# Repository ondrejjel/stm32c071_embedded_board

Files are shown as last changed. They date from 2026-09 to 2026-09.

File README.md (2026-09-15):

# STM32C071 Development Board

A compact, portable embedded development board built around the **STM32C071K8T6** microcontroller.

The board was designed as a personal platform for embedded firmware development, hardware experimentation, and prototyping. The focus is on providing a reasonably complete development environment in a small form factor while keeping important interfaces accessible for debugging and experimentation.

> **Status:** Rev. 1 PCB manufactured.

## Features

### MCU

* **STM32C071K8T6**
* ARM Cortex-M0+ core
* LQFP-32 package
* SWD programming and debugging
* Dedicated RESET and BOOT0 buttons

### Memory

* **16 MB SPI NOR flash**
* Winbond **W25Q128JV**
* Dedicated SPI interface
* Accessible through exposed test points

### Security

* **ATECC608A** secure element
* I²C interface
* Intended for experimentation with hardware-backed cryptography, secure key storage, and device identity

### USB

* USB-C receptacle
* USB 2.0 interface
* **USBLC6-4SC6** ESD protection

### Power

* 5 V input
* **MCP1825S-330** 3.3 V LDO
* Exposed 5 V and 3.3 V test points
* Multiple ground test points

### User Interface

* 5 user buttons
* Dedicated RESET button
* Dedicated BOOT0 button
* Dedicated red power indicator LED
* 5 user LEDs:

  * 1× red
  * 1× green
  * 1× blue
  * 1× orange
  * 1× yellow

### Debugging & Test

The board includes numerous test points to make hardware bring-up and debugging easier.

Exposed signals include:

* SWDIO
* SWCLK
* NRST
* BOOT0
* UART TX/RX
* SPI CS
* SPI CLK
* SPI DI
* SPI DO
* I²C SDA/SCL
* 5 V
* 3.3 V
* GND

An **STDC14** debug connector is also provided.

## Hardware Architecture

The main hardware blocks are:

```text
                         ┌──────────────────┐
                    -----│    USB-C Input   │
                    │    └────────┬─────────┘
                    │             │
                   USB           5 V
                    │             │
                    │    ┌────────▼─────────┐
                    │    │   Power / 3.3 V  │
                    │    │     MCP1825S     │
                    │    └────────┬─────────┘
                    │             │ 
                 ┌──▼─────────────▼────────────────┐
                 │          STM32C071K8T6           │
                 │                                 │
                 │  GPIO   SPI   I²C   USB   SWD   │
                 └───┬─────┬─────┬─────┬────┬─────┘
                     │     │     │     │    │
                     │     │     │     │    └── Debug
                     │     │     │     │
                     │     │     │     └──── USB
                     │     │     │
                     │     │     └──────── ATECC608A
                     │     │
                     │     └────────────── W25Q128JV
                     │
                     └────────────────── Buttons / LEDs
```

The exact peripheral assignments are defined in the schematic and firmware configuration.

## PCB Design

The schematic and PCB were designed entirely in **KiCad**.

The board was designed around several goals:

* compact and portable form factor
* practical access to debugging interfaces
* dedicated test points for important signals
* integrated external memory
* hardware security experimentation
* simple power architecture
* useful user I/O
* easy hardware bring-up

The PCB was manufactured by **JLCPCB**.

## Bring-up Plan

Once the assembled board is available, hardware bring-up will be performed incrementally.

### 1. Power

* Inspect the assembled PCB
* Check for shorts before applying power
* Verify 5 V input
* Verify 3.3 V regulator output
* Measure idle current consumption

### 2. MCU

* Connect through SWD
* Verify MCU identification
* Test RESET
* Verify BOOT0 operation
* Flash a minimal test program

### 3. GPIO

* Test user buttons
* Test LEDs
* Verify GPIO levels and mappings

### 4. SPI Flash

* Verify SPI signals with a logic analyzer
* Read the JEDEC ID
* Test read/write operations
* Verify the full memory interface

### 5. I²C / Secure Element

* Verify I²C electrical levels
* Detect the ATECC608A
* Establish communication
* Test basic device functionality

### 6. USB

* Verify USB power and signal integrity
* Test USB enumeration
* Develop and validate the intended USB functionality

Any hardware problems discovered during bring-up will be documented in this repository.

## Test Points

The board intentionally exposes important signals for external measurement.

| Signal | Purpose |
| --- | --- |
| GND | Ground reference |
| 5V | Main 5 V rail |
| 3V3 | Regulated 3.3 V rail |
| NRST | MCU reset |
| BOOT0 | Boot configuration |
| SWDIO | SWD data |
| SWCLK | SWD clock |
| TX | UART transmit |
| RX | UART receive |
| CS | SPI chip select |
| CLK | SPI clock |
| DI | SPI data input |
| DO | SPI data output |
| SDA | I²C data |
| SCL | I²C clock |
| USERBTN1–5 | User button signals  |

## Repository Structure

```text
.
├── hardware/
│   ├── schematic/
│   ├── pcb/
│   └── fabrication/
├── firmware/
├── docs/
├── LICENSE
└── README.md
```

The structure may evolve as firmware and documentation are added.

## Design Files

The KiCad project contains the complete schematic and PCB design.

Manufacturing files are included so that future revisions can be reproduced or modified.

## Bill of Materials

The main active components are:

| Reference | Component | Purpose |
| --- | --- | --- |
| U1 | STM32C071K8T6 | Main MCU |
| U2 | ATECC608A-SSHDA | Secure element |
| U3 | W25Q128JV | 16 MB SPI flash |
| U4 | USBLC6-4SC6 | USB ESD protection |
| U5 | MCP1825S-330E | 3.3 V LDO |
| J1 | STDC14 | Debug/programming connector |
| J2 | USB-C | USB/power connection |

The complete BOM is available in the hardware project files.

## Project Status

| Area | Status |
| --- | --- |
| Schematic | Complete |
| PCB layout | Complete |
| Manufacturing files | Complete |
| PCB manufacturing | In progress |
| Assembly | Pending |
| Hardware bring-up | Pending |
| Firmware | Planned |

## Lessons & Revision History

This is my first custom PCB project, so the first revision is also intended as a learning platform.

Rather than treating Rev. 1 as a final design, the goal is to use the board to identify:

* schematic mistakes
* layout issues
* component selection problems
* power-related issues
* signal integrity problems
* usability improvements

Findings from the first hardware revision will be documented here and used to guide future revisions.

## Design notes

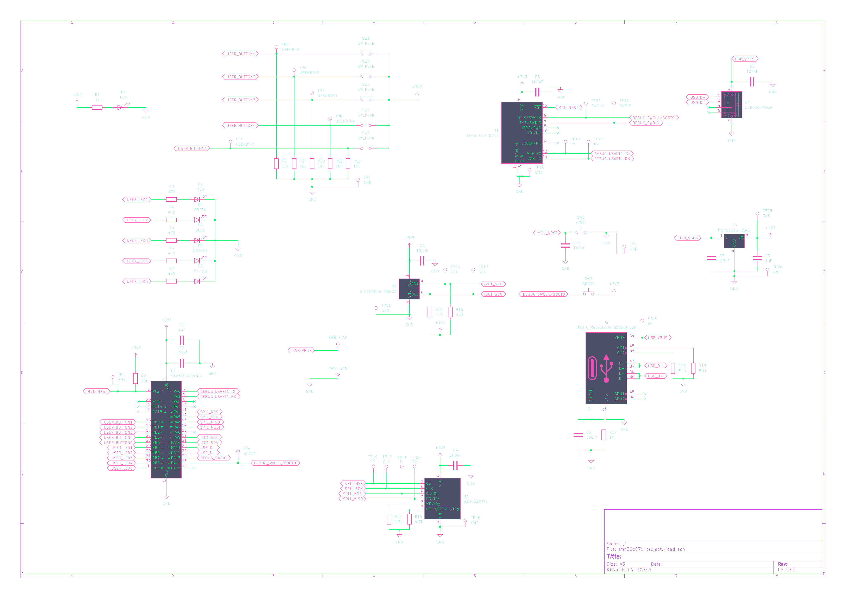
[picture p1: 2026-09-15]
hardware/schematics/image.png

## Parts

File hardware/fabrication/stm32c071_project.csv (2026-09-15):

Reference | Qty | Value | DNP | Exclude from BOM | Exclude from Board | Exclude from Simulation | Exclude from Position Files | Footprint | Datasheet
C1,C9 | 2 | 1uF |  |  |  |  | ${EXCLUDE_FROM_POS_FILES} | Capacitor_SMD:C_0603_1608Metric
C2,C3,C4,C5,C6,C8,C10 | 7 | 100nF |  |  |  |  | ${EXCLUDE_FROM_POS_FILES} | Capacitor_SMD:C_0603_1608Metric
C7 | 1 | 4.7uF |  |  |  |  | ${EXCLUDE_FROM_POS_FILES} | Capacitor_SMD:C_0603_1608Metric
D1,D2 | 2 | RED |  |  |  |  | ${EXCLUDE_FROM_POS_FILES} | LED_SMD:LED_0603_1608Metric
D3 | 1 | GREEN |  |  |  |  | ${EXCLUDE_FROM_POS_FILES} | LED_SMD:LED_0603_1608Metric
D4 | 1 | BLUE |  |  |  |  | ${EXCLUDE_FROM_POS_FILES} | LED_SMD:LED_0603_1608Metric
D5 | 1 | ORANGE |  |  |  |  | ${EXCLUDE_FROM_POS_FILES} | LED_SMD:LED_0603_1608Metric
D6 | 1 | YELLOW |  |  |  |  | ${EXCLUDE_FROM_POS_FILES} | LED_SMD:LED_0603_1608Metric
J1 | 1 | Conn_ST_STDC14 |  |  |  |  | ${EXCLUDE_FROM_POS_FILES} | Connector_PinHeader_1.27mm:PinHeader_2x07_P1.27mm_Vertical | https://www.st.com/content/ccc/resource/technical/document/user_manual/group1/99/49/91/b6/b2/3a/46/e5/DM00526767/files/DM00526767.pdf/jcr:content/translations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
J2 | 1 | USB_C_Receptacle_USB2.0_16P |  |  |  |  | ${EXCLUDE_FROM_POS_FILES} | Connector_USB:USB_C_Receptacle_GCT_USB4110 | https://www.usb.org/sites/default/files/documents/usb_type-c.zip
R1 | 1 | 1k |  |  |  |  | ${EXCLUDE_FROM_POS_FILES} | Resistor_SMD:R_0603_1608Metric
R2,R8,R9,R10,R11,R12 | 6 | 10k |  |  |  |  | ${EXCLUDE_FROM_POS_FILES} | Resistor_SMD:R_0603_1608Metric
R3,R4,R5,R6,R7 | 5 | 470 |  |  |  |  | ${EXCLUDE_FROM_POS_FILES} | Resistor_SMD:R_0603_1608Metric
R13,R14,R15,R16 | 4 | 4.7k |  |  |  |  | ${EXCLUDE_FROM_POS_FILES} | Resistor_SMD:R_0603_1608Metric
R17 | 1 | 1M |  |  |  |  | ${EXCLUDE_FROM_POS_FILES} | Resistor_SMD:R_0603_1608Metric
R18,R19 | 2 | 5.1k |  |  |  |  | ${EXCLUDE_FROM_POS_FILES} | Resistor_SMD:R_0603_1608Metric
SW1,SW2,SW3,SW4,SW5 | 5 | SW_Push |  |  |  |  | ${EXCLUDE_FROM_POS_FILES} | Button_Switch_SMD:SW_Push_SPST_NO_Alps_SKRK
SW6 | 1 | RESET |  |  |  |  | ${EXCLUDE_FROM_POS_FILES} | Button_Switch_SMD:SW_Push_SPST_NO_Alps_SKRK
SW7 | 1 | BOOT0 |  |  |  |  | ${EXCLUDE_FROM_POS_FILES} | Button_Switch_SMD:SW_Push_SPST_NO_Alps_SKRK
TP1 | 1 | NRST |  |  |  |  | ${EXCLUDE_FROM_POS_FILES} | TestPoint:TestPoint_Pad_D1.0mm
TP2,TP9,TP11,TP16,TP18,TP26 | 6 | GND |  |  |  |  | ${EXCLUDE_FROM_POS_FILES} | TestPoint:TestPoint_Pad_1.0x1.0mm
TP3 | 1 | USERBTN5 |  |  |  |  | ${EXCLUDE_FROM_POS_FILES} | TestPoint:TestPoint_Pad_D1.0mm
TP4 | 1 | BOOT0 |  |  |  |  | ${EXCLUDE_FROM_POS_FILES} | TestPoint:TestPoint_Pad_D1.0mm
TP5 | 1 | USERBTN1 |  |  |  |  | ${EXCLUDE_FROM_POS_FILES} | TestPoint:TestPoint_Pad_D1.0mm
TP6 | 1 | USERBTN2 |  |  |  |  | ${EXCLUDE_FROM_POS_FILES} | TestPoint:TestPoint_Pad_D1.0mm
TP7 | 1 | USERBTN3 |  |  |  |  | ${EXCLUDE_FROM_POS_FILES} | TestPoint:TestPoint_Pad_D1.0mm
TP8 | 1 | USERBTN4 |  |  |  |  | ${EXCLUDE_FROM_POS_FILES} | TestPoint:TestPoint_Pad_D1.0mm
TP10 | 1 | CS |  |  |  |  | ${EXCLUDE_FROM_POS_FILES} | TestPoint:TestPoint_Pad_D1.0mm
TP12 | 1 | CLK |  |  |  |  | ${EXCLUDE_FROM_POS_FILES} | TestPoint:TestPoint_Pad_D1.0mm
TP13 | 1 | DI |  |  |  |  | ${EXCLUDE_FROM_POS_FILES} | TestPoint:TestPoint_Pad_D1.0mm
TP14 | 1 | DO |  |  |  |  | ${EXCLUDE_FROM_POS_FILES} | TestPoint:TestPoint_Pad_D1.0mm
TP15 | 1 | SDA |  |  |  |  | ${EXCLUDE_FROM_POS_FILES} | TestPoint:TestPoint_Pad_D1.0mm
TP17 | 1 | SCL |  |  |  |  | ${EXCLUDE_FROM_POS_FILES} | TestPoint:TestPoint_Pad_D1.0mm
TP19 | 1 | TX |  |  |  |  | ${EXCLUDE_FROM_POS_FILES} | TestPoint:TestPoint_Pad_D1.0mm
TP20 | 1 | SWCLK |  |  |  |  | ${EXCLUDE_FROM_POS_FILES} | TestPoint:TestPoint_Pad_D1.0mm
TP21 | 1 | RX |  |  |  |  | ${EXCLUDE_FROM_POS_FILES} | TestPoint:TestPoint_Pad_D1.0mm
TP22 | 1 | SWDIO |  |  |  |  | ${EXCLUDE_FROM_POS_FILES} | TestPoint:TestPoint_Pad_D1.0mm
TP24 | 1 | 5V |  |  |  |  | ${EXCLUDE_FROM_POS_FILES} | TestPoint:TestPoint_Pad_D1.0mm
TP25 | 1 | 3V3 |  |  |  |  | ${EXCLUDE_FROM_POS_FILES} | TestPoint:TestPoint_Pad_D1.0mm
U1 | 1 | STM32C071K8Tx |  |  |  |  | ${EXCLUDE_FROM_POS_FILES} | Package_QFP:LQFP-32_7x7mm_P0.8mm | https://www.st.com/resource/en/datasheet/stm32c071k8.pdf
U2 | 1 | ATECC608A-SSHDA |  |  |  |  | ${EXCLUDE_FROM_POS_FILES} | Package_SO:SOIC-8_3.9x4.9mm_P1.27mm | http://ww1.microchip.com/downloads/en/DeviceDoc/ATECC608A-CryptoAuthentication-Device-Summary-Data-Sheet-DS40001977B.pdf
U3 | 1 | W25Q128JVS |  |  |  |  | ${EXCLUDE_FROM_POS_FILES} | Package_SO:SOIC-8_5.3x5.3mm_P1.27mm | https://www.winbond.com/resource-files/w25q128jv_dtr%20revc%2003272018%20plus.pdf
U4 | 1 | USBLC6-4SC6 |  |  |  |  | ${EXCLUDE_FROM_POS_FILES} | Package_TO_SOT_SMD:SOT-23-6 | https://www.st.com/resource/en/datasheet/usblc6-4.pdf
U5 | 1 | MCP1825S-330E |  |  |  |  | ${EXCLUDE_FROM_POS_FILES} | Package_TO_SOT_SMD:SOT-223-3_TabPin2 | http://ww1.microchip.com/downloads/en/devicedoc/22056b.pdf

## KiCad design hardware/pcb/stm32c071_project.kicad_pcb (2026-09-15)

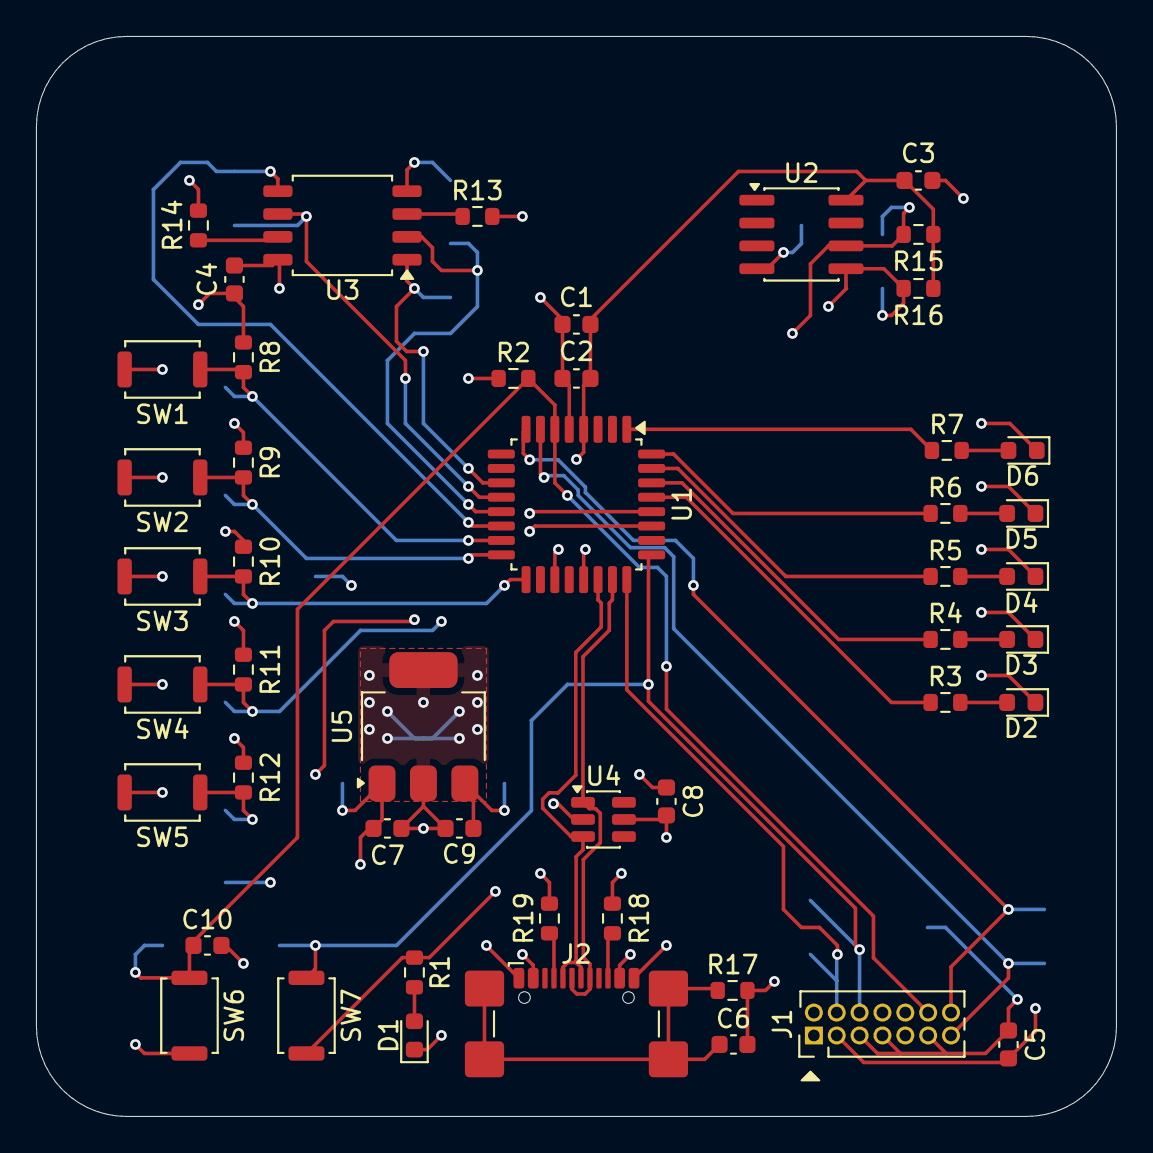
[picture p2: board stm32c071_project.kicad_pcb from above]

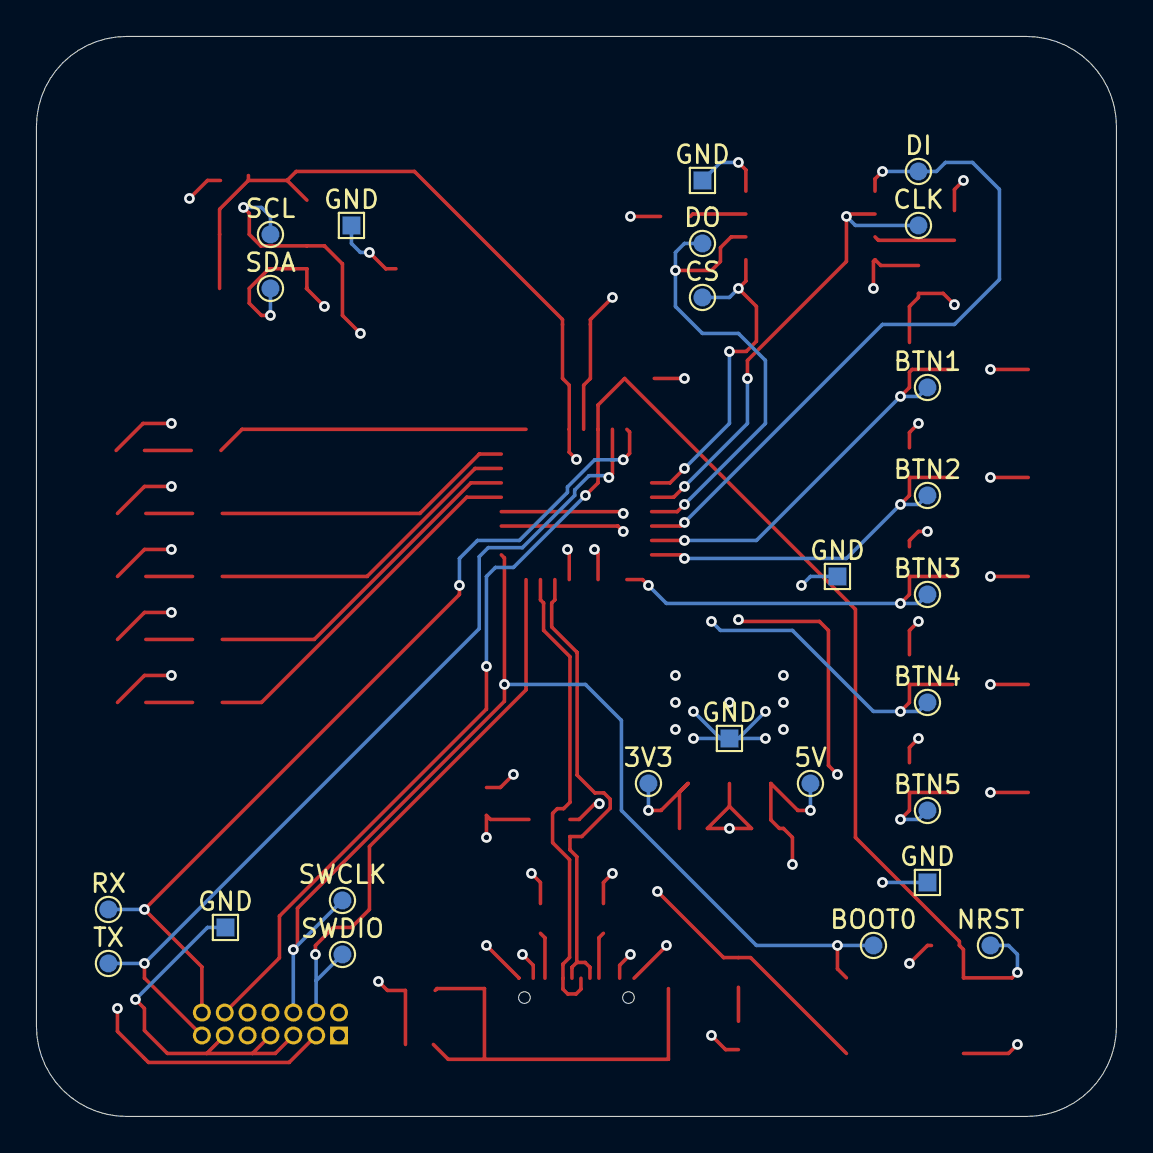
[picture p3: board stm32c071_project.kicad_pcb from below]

Board: 4 copper layers, 60.0 x 60.0 mm, 74 parts (25 on the bottom side), 37 nets.

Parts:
3V3: 3V3; TestPoint_Pad_D1.0mm
5V: 5V; TestPoint_Pad_D1.0mm
BOOT0: BOOT0; TestPoint_Pad_D1.0mm
BTN1: USERBTN1; TestPoint_Pad_D1.0mm
BTN2: USERBTN2; TestPoint_Pad_D1.0mm
BTN3: USERBTN3; TestPoint_Pad_D1.0mm
BTN4: USERBTN4; TestPoint_Pad_D1.0mm
BTN5: USERBTN5; TestPoint_Pad_D1.0mm
C1, C9: 1uF; C_0603_1608Metric
C2, C3, C4, C5, C6, C8, C10: 100nF; C_0603_1608Metric
C7: 4.7uF; C_0603_1608Metric
CLK: CLK; TestPoint_Pad_D1.0mm
CS: CS; TestPoint_Pad_D1.0mm
D1, D2: RED; LED_0603_1608Metric
D3: GREEN; LED_0603_1608Metric
D4: BLUE; LED_0603_1608Metric
D5: ORANGE; LED_0603_1608Metric
D6: YELLOW; LED_0603_1608Metric
DI: DI; TestPoint_Pad_D1.0mm
DO: DO; TestPoint_Pad_D1.0mm
GND: GND; TestPoint_Pad_1.0x1.0mm
GND#2, GND#3, GND#4, GND#5, GND#6: GND; TestPoint_Pad_1.0x1.0mm
J1: Conn_ST_STDC14; PinHeader_2x07_P1.27mm_Vertical
J2: USB_C_Receptacle_USB2.0_16P; USB_C_Receptacle_GCT_USB4110
NRST: NRST; TestPoint_Pad_D1.0mm
R1: 1k; R_0603_1608Metric
R2, R8, R9, R10, R11, R12: 10k; R_0603_1608Metric
R3, R4, R5, R6, R7: 470; R_0603_1608Metric
R13, R14, R15, R16: 4.7k; R_0603_1608Metric
R17: 1M; R_0603_1608Metric
R18, R19: 5.1k; R_0603_1608Metric
RX: RX; TestPoint_Pad_D1.0mm
SCL: SCL; TestPoint_Pad_D1.0mm
SDA: SDA; TestPoint_Pad_D1.0mm
SW1, SW2, SW3, SW4, SW5: SW_Push; SW_Push_SPST_NO_Alps_SKRK
SW6: RESET; SW_Push_SPST_NO_Alps_SKRK
SW7: BOOT0; SW_Push_SPST_NO_Alps_SKRK
SWCLK: SWCLK; TestPoint_Pad_D1.0mm
SWDIO: SWDIO; TestPoint_Pad_D1.0mm
TX: TX; TestPoint_Pad_D1.0mm
U1: STM32C071K8Tx; LQFP-32_7x7mm_P0.8mm
U2: ATECC608A-SSHDA; SOIC-8_3.9x4.9mm_P1.27mm
U3: W25Q128JVS; SOIC-8_5.3x5.3mm_P1.27mm
U4: USBLC6-4SC6; SOT-23-6
U5: MCP1825S-330E; SOT-223-3_TabPin2

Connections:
+3V3: 3V3.1 (1_1), C1.1, C2.1, C3.1, C4.1, C5.1, C9.1, J1.3 (VCC), R1.1, R2.1, R15.2, R16.2, SW1.2, SW2.2, SW3.2, SW4.2, SW5.2, SW7.2, U1.4 (VDD), U2.8 (VCC), U3.8 (VCC), U5.3 (VO)
DEBUG_SWCLK/BOOT0: BOOT0.1 (1_1), J1.6 (JCLK/SWCLK), SW7.1, SWCLK.1 (1_1), U1.25 (PA14)
DEBUG_SWDIO: J1.4 (JTMS/SWDIO), SWDIO.1 (1_1), U1.24 (PA13)
DEBUG_USART1_RX: J1.14 (VCP_TX), RX.1 (1_1), U1.8 (PA1)
DEBUG_USART1_TX: J1.13 (VCP_RX), TX.1 (1_1), U1.7 (PA0)
GND: C1.2, C2.2, C3.2, C4.2, C5.2, C6.2, C7.2, C8.2, C9.2, C10.2, D1.1 (K), D2.1 (K), D3.1 (K), D4.1 (K), D5.1 (K), D6.1 (K), GND.1 (1_1), GND#2.1 (1_1), GND#3.1 (1_1), GND#4.1 (1_1), GND#5.1 (1_1), GND#6.1 (1_1), J1.5 (GND), J1.7 (GND), J1.11 (GNDDetect), J2.A1 (GND), J2.A12 (GND), J2.B1 (GND), J2.B12 (GND), R8.2, R9.2, R10.2, R11.2, R12.2, R13.2, R14.2, R17.2, R18.2, R19.2, SW6.2, U1.5 (VSS), U2.4 (GND), U3.4 (GND), U4.2 (GND), U5.2 (GND)
I2C1_SCL: R16.1, SDA.1 (1_1), U1.19 (PA9), U2.5 (SDA)
I2C1_SDA: R15.1, SCL.1 (1_1), U1.21 (PA10), U2.6 (SCL)
MCU_NRST: C10.1, J1.12 (~RST), NRST.1 (1_1), R2.2, SW6.1, U1.6 (PF2)
unnamed: D1.2 (A), R1.2
unnamed: D2.2 (A), R3.2
unnamed: D3.2 (A), R4.2
unnamed: D4.2 (A), R5.2
unnamed: D5.2 (A), R6.2
unnamed: D6.2 (A), R7.2
unnamed: J2.A5 (CC1), R19.1
unnamed: J2.B5 (CC2), R18.1
unnamed: C6.1, J2.SH (SHIELD), R17.1
unnamed: R14.1, U3.7 (~HOLD/~RESET/IO_{3})
unnamed: R13.1, U3.3 (~WP/IO_{2})
SPI1_MISO: DO.1 (1_1), U1.13 (PA6), U3.2 (DO/IO_{1})
SPI1_MOSI: DI.1 (1_1), U1.14 (PA7), U3.5 (DI/IO_{0})
SPI1_NSS: CS.1 (1_1), U1.11 (PA4), U3.1 (~CS)
SPI1_SCK: CLK.1 (1_1), U1.12 (PA5), U3.6 (CLK)
USB_D+: J2.A6 (D+), J2.B6 (D+), U1.23 (PA12), U4.1 (I/O1)
USB_D-: J2.A7 (D-), J2.B7 (D-), U1.22 (PA11), U4.3 (I/O2)
USB_VBUS: 5V.1 (1_1), C7.1, C8.1, J2.A4 (VBUS), J2.A9 (VBUS), J2.B4 (VBUS), J2.B9 (VBUS), U4.5 (VBUS), U5.1 (VI)
USER_BUTTON1: BTN1.1 (1_1), R8.1, SW1.1, U1.15 (PB0)
USER_BUTTON2: BTN2.1 (1_1), R9.1, SW2.1, U1.16 (PB1)
USER_BUTTON3: BTN3.1 (1_1), R10.1, SW3.1, U1.17 (PB2)
USER_BUTTON4: BTN4.1 (1_1), R11.1, SW4.1, U1.27 (PB3)
USER_BUTTON5: BTN5.1 (1_1), R12.1, SW5.1, U1.28 (PB4)
USER_LED1: R3.1, U1.29 (PB5)
USER_LED2: R4.1, U1.30 (PB6)
USER_LED3: R5.1, U1.31 (PB7)
USER_LED4: R6.1, U1.32 (PB8)
USER_LED5: R7.1, U1.1 (PB9)
